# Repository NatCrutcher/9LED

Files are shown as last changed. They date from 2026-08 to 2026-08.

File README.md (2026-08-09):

## Overview

This is a small test PCB to experiment with wide color gamut LEDs. The initial plan is to use the following LEDs, driven by the TI TLC5971 (high-quality 16-bit PWM).

1. Violet 410 (XE-G)
2. Blue PC 460 (OSLON)
3. Cyan 500 (XE-G)
4. Green 525 (OSLON)
5. Yellow PC 590 (OSLON)
6. Red 620 (OSLON)
7. Photo Red 660 (XE-G)
8. Far Red 735 (Luxeon)
9. White (OSLON)

This should allow tests to compare more traditional RGB and RGBW color gamuts to wider gamuts. In particular, deeper reds, violet, and cyan. 

### Cyan
Initial testing shows that the cyan LED makes a color that is perceptually different from just mixing various amounts of green and blue. Green+blue results in the traditional computer monitor "cyan", which is really more turquoise. The pure cyan LED results in a more saturated (computer monitor cyan is a bit pastel by comparison) strong green-blue color.

### Violet

By itself, the violet LED is not what I expected: it seems almost like a purple/blue/white mixture. I need to do more research to make sure it is not exciting the phosphors in the white LED (perhaps build a board without the white). My plans are to compare purples (red+blue and red+violet) to see if violet generates noticeably different (i.e. more intense) purpl

### Photo Red and Far Red

This is an interesting example of how our eyes acclimate, color balance, and otherwise shift our perceptions. When I look at the normal red LED, it looks strongly red. But when I look at normal red next to photo red, the photo red looks more intensely red and the normal red starts to look like an orange-red. I want to try a larger experiment to determine how this effect scales.

The far red appears to be useless for LED sculptures, animations, or lighting. The perceived brightness is MUCH (like 10-20X) lower, so it can only produce very dim illumination. And as seen on the chromaticity diagrams, the perceived color is very close to photo red, so it does not meaningfully increase the gamut.

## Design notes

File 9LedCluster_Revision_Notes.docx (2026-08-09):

# 9 LED Cluster – Revision Notes

# Revision v1 – 2025-02-01

- First revision

# Revision v2 – 2025-09-22

## General

- No: Add some test points.
- DONE: Remove J1 and J2 pads from the paste mask.
- DONE: Move pad labels to the bottom so that I can make the board narrower. Or remove altogether.
- DONE: Document the mounting hole sizes on the schematic.
- DONE: Remove thermal reliefs for the mounting holes to the ground plane.
- DONE: Renumber designators.
- DONE: Try with 0603 to see if it makes the board larger.
- DONE: Change to 4-layer PCB.
- No: Consider metal core PCB
- Future: Add fiducials
- No: Try single-layer PCB design with zero-ohm jumpers instead of bottom layer tracks. This might allow an inexpensive metal core PCB and better heatsinking.
- DONE: Make room for a fourth corner hole.
- Future: Consider adding some thermistors to measure temperatures. Perhaps with I2C DAQ.

## Power Supply

- DONE: Update Vreg feedback calcs. R5 and R6 are reversed.
- DONE: Change to 4.0 V output.
- Skip for now: Can I find a buck converter with a higher switching frequency and a smaller inductor? – Yes, higher freq (2.0 MHz vs 1.1 MHz), the inductor drops from 15μH to 10μH, but ends up the same size. Consider integrated converter.
- Skip for now: Consider DC-DC module like TI TPSM33615.
- DONE: Replace R7 with a ferrite bead.
- Future: Consider one FB at J1 and one at J2. Or use CM choke at each end.
  - Murata BLM15AG601SH1D 0402, 600Ω @ 100 MHz, DCR=0.6Ω
- DONE: Route the Vin track on the third layer and further from the buck regulator to avoid noise coupling.
- Somewhat done: Surround the buck regulator switching nodes with ground.
- DONE: Consider an isolated ground plane with single connection for the buck regulator.
- Future: Test conducted RF from the regulator onto the Vin and Vout leads.
- DONE: Changed buck output cap from 1206 to 0805.
- DONE: Test at Vcc = 4.0 and 4.25 V to see how it affects the heating. Make sure we won’t overvoltage the SPI inputs (Vcc+0.6 abs max). Use the same Vcc for the level shifter.
  - Vcc = 4.0 V works well
- Future: Consider UVLO on the power supply
- DONE: Protect against reverse polarity connection, if not too difficult.
  - Diotec SKM14 Schottky, 40V, 1A, SOD-123FL, 350mV@1A

## LED Driver

- DONE: Disconnect VREG from VCC so the SPI levels will be 3.3V. Add a 1.0μF bypass cap on VREG.
- Future: Protect SDTI and SCKI from exceeding Vcc+0.6, perhaps with Schottky diodes or SOT-23 input protection diodes to Vcc. Maybe also series current limiting resistors.
- Future: Consider 3-terminal feed through capacitors. Maybe replace five 0.22uF with 1-2 three-terminal caps.
  - https://product.tdk.com/en/techlibrary/solutionguide/yff-series.html
- DONE: Add dropping diodes or resistors for lower Vf diodes, like red and amber. This will reduce the heating in the TLC5971. These could be populated with zero-ohm jumpers when not needed. It looks like 0603 resistors would be best, 16.0 or 16.5 ohm for 60 mA, only for LEDs with ~2.0 Vf.
  - Rohm ESR03EZPF16R5, 16.5Ω, 1%, 0.25W, 100 ppm/°C, thick film, 0603
  - Panasonic ERJ-PA3F16R0V, 16.0Ω, 1%, 0.33W, 100 ppm/°C, thick film, 0603
  - Vishay Dale CRCW06038R20FKEAHP, 8.2Ω, 1%, 0.33W, 100 ppm/°C, thick film, 0603
- Skip: Consider dual drivers to allow 2X the power. Would likely overheat the PCB and LEDs.

## LEDs

- DONE: Center LEDs on the PCB and align the corner holes to be symmetrical.
- DONE: Larger LED cathode mark in copper (it’s not really visible). Or remove and just use silkscreen.
- DONE: For the Luxeon CZ LEDs, make LED pads slightly taller, maybe 0.1 to 0.2 mm on each end (right now, they are fully covered on both ends).
- DONE: Consider LED diffuser mounting holes.
- DONE: Leave a clear margin around the LEDs for light shaping / diffusing
- DONE: Leave ~1mm between LEDs for barrier to block blue/violet from white phosphors. This may not be needed if I use flat top LEDs (no lens).
- DONE: Use a mixture of OSLON Pure 1414, Cree XE-G, and Luxeon CZ LED since we are only driving 60 mA to 120 mA. This will save money and space.
- DONE: Change to a shorter wavelength violet (410 nm instead of 425 nm)

# Revision v2b – 2025-10-08

## General

- Remove corner holes from the solder paste stencil.
- Adjust solder paste expansion.
- Adjust solder paste stencil size and thickness.

# Revision v3 – tbd

## Future

- Add fiducials

## LED List

1. Violet 410 (XE-G)
2. Blue PC 460 (OSLON)
3. Cyan 500 (XE-G)
4. Green 525 (OSLON)
5. Yellow PC 590 (OSLON)
6. Red 620 (OSLON)
7. Photo Red 660 (XE-G)
8. Far Red 735 (Luxeon)
9. White (OSLON)

Yellow PC | Red | Blue PC
White | Photo Red | Cyan
Green | Far Red | Violet

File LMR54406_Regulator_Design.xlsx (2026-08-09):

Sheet: Design
Inductor
Vout | Vin_max | L |  | fSW | ΔiL | Iout_max | K_IND | Lmin | Lrms | Lsat
4.5 | 25 | 1.5e-05 |  | 1100000 | 0.224 | 0.550 | 40.66115702% | 1.5e-05 | 0.825 | 1.375
4.0 | 25 | 1.5e-05 |  | 1100000 | 0.204 | 0.550 | 37.02479339% | 1.5e-05 | 0.825 | 1.375
Recheck the Lmin for 4.0 Vout
Regulator Feedback
R5 (R_FBT) | Vcc | R6 (R_FBB) Target | R6 Actual | R5+R6 Actual | Ifb | Pr5 | Pr6 | Pfb | Check Vcc
23200 | 5.0 | 121800 | 121000 | 144200 | 3.46740638e-05 | 2.789314425e-05 | 0.0001464390073 | 0.0001743321516 | 4.972
23200 | 4.5 | 107300 | 107000 | 130200 | 3.456221198e-05 | 2.771347873e-05 | 0.0001281748391 | 0.0001558883179 | 4.490
23200 | 4.0 | 92800 | 93100 | 116300 | 3.439380911e-05 | 2.744407125e-05 | 0.000109776285 | 0.0001372203562 | 4.010
23200 | 4.5 | 107300 | 107000 | 130200 | 3.456221198e-05 | 2.771347873e-05 | 0.0001281748391 | 0.0001558883179 | 4.490
23200 | 4.0 | 92800 | 93100 | 116300 | 3.439380911e-05 | 2.744407125e-05 | 0.000109776285 | 0.0001372203562 | 4.010
18000 | 4.0 | 72000 | 75000 | 93000 | 4.301075269e-05 | 3.329864724e-05 | 0.000133194589 | 0.0001664932362 | 4.133
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

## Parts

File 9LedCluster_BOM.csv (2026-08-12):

NccId | Qty | Reference | Value | Type | DNP | Manufacturer | MPN | Price10 | Rating | Tolerance | Rating2 | Description | Package | Footprint | Vendor1 | Vendor1PN | Vendor2 | Vendor2PN
p0F | 1 | D8 | Far Red | Luxeon C |  | Lumileds | L1C1-FRD1000000000 | 2.42 | 350mA |  |  | LED Luxeon C Far Red 2.0x2.0 350mA | LED 0808 | NwcPcbLibrary:Luxeon_CZ_LED_AK | Digi-Key | 1416-1913-1-ND | Mouser | 997-L1C1-FRD10000000
p03 | 1 | D7 | Green | Pure 1414 |  | ams-OSRAM | GT VJLPL1.13-LPLS-T3T4-1 | 1.01 | 350mA |  |  | LED Pure 1414 Green 1.4x1.4 350mA | LED 0505 | NwcPcbLibrary:OSRAM-OSLON-Pure-1414 | Digi-Key | 475-GTVJLPL1.13-LPLS-T3T4-1-350-R18CT-ND | Mouser | 720-GTVL113LPLST3T41
p04 | 1 | D2 | Red | Pure 1414 |  | ams-OSRAM | GR VJLPL1.23-KQKS-A4R2-1 | 1.04 | 350mA |  |  | LED Pure 1414 Red 1.4x1.4 350mA | LED 0505 | NwcPcbLibrary:OSRAM-OSLON-Pure-1414 | Digi-Key | 475-GRVJLPL1.23-KQKS-A4R2-1-350-R18CT-ND | Mouser | 720-GRVL123KQKSA4R21
p05 | 1 | D4 | White 4000K | Pure 1414 |  | ams-OSRAM | GW VJLPL1.CM-K3LX-XX55-1 | 1.013 | 350mA |  |  | LED Pure 1414 White 4000K 1.4x1.4 350mA | LED 0505 | NwcPcbLibrary:OSRAM-OSLON-Pure-1414 | Digi-Key | 475-GWVJLPL1.CM-K3LX-XX55-1-350-R18CT-ND | Mouser | 720-GWVL1CMK3LXXX551
p15 | 1 | D1 | Yellow PC | Pure 1414 |  | ams-OSRAM | GY VJLPL1.F3-KULQ-YCYK-1 | 0.748 | 350mA |  |  | LED Pure 1414 Yellow PC 1.4x1.4 350mA | LED 0505 | NwcPcbLibrary:OSRAM-OSLON-Pure-1414 | Digi-Key | 475-GYVJLPL1.F3-KULQ-YCYK-1-350-R18CT-ND | Mouser | 720-GYVL1F3KULQYCYK1
p16 | 1 | D9 | PC Blue | Pure 1414 |  | ams-OSRAM | GB VJLPL1.F3-JRJT-BABB-1 | 1.024 | 350mA |  |  | LED Pure 1414 PC Blue 1.4x1.4 350mA | LED 0505 | NwcPcbLibrary:OSRAM-OSLON-Pure-1414 | Digi-Key | 475-GBVJLPL1.F3-JRJT-BABB-1CT-ND | Mouser | 720-GBVL1F3JRJTBABB1
p17 | 1 | D3 | Violet | XE-G |  | Cree | XEGAVT-H0-0000-000-000000K2001 | 3.819 | 1A |  |  | LED XE-G Violet 2.05x1.6 1A | LED 0806 | NwcPcbLibrary:Cree_XE-G | Digi-Key | 90-XEGAVT-H2-0000-000-000000K2001CT-ND | Mouser | 941-XEGAVTH000K2001
p18 | 1 | D5 | Photo Red | XE-G |  | Cree | XEGAHR-H2-0000-000-000000H6001 | 2.73 | 1A |  |  | LED XE-G Photo Red 2.05x1.6 1A | LED 0806 | NwcPcbLibrary:Cree_XE-G | Digi-Key | 90-XEGAHR-H2-0000-000-000000H6001CT-ND | Mouser | 941-XEGAHRH200H6001
p19 | 1 | D6 | Cyan | XE-G |  | Cree | XEGACY-H2-0000-000-000000T3001 | 3 | 1A |  |  | LED XE-G Cyan 2.05x1.6 1A | LED 0806 | NwcPcbLibrary:Cree_XE-G | Digi-Key | 90-XEGACY-H0-0000-000-000000S5001CT-ND | Mouser | 941-XEGACYH20T3001
n05 | 1 | L1 | 15uH | Shielded, drum |  | TDK | BCL322520RT-150M-D | 1.09 | I=1.47 | 20% | 320 mOhm Max | inductor 15uH Shielded, drum 3.2x2.5 I=1.47 | Ind 3.2x2.5mm | Inductor_SMD:L_1210_3225Metric | Digi-Key | 445-BCL322520RT-150M-DCT-ND | Mouser | 810-BCL322520RT150MD
n07 | 1 | FB1 | 600Ω | Ferrite Bead |  | Murata Electronics | BLM18KG601SN1D | 0.062 | 1.3A |  | DCR=150mΩ | ferrite 600Ω 0603 1.3A | 0603 | Resistor_SMD:R_0603_1608Metric_Pad0.98x0.95mm_HandSolder | Digi-Key | 490-5258-1-ND
k05 | 1 | U2 | TLC5971 | LED PWM driver |  | TI | TLC5971RGER | 2.342 | 17V, 60mA |  | 12ch, 16bit | IC TLC5971 LED PWM driver VQFN-24 4x4mm_P0.5mm TI | VQFN-24 4x4mm_P0.5mm | Package_DFN_QFN:Texas_RGE0024H_VQFN-24-1EP_4x4mm_P0.5mm_EP2.7x2.7mm_ThermalVias | Digi-Key | 296-28448-1-ND | Mouser | 595-TLC5971RGER
k16 | 1 | U1 | LMR54406 | Regulator, Buck |  | TI | LMR54406DBVR | 0.86 | 1.1MHz |  | 600mA | IC LMR54406 Regulator, Buck SOT-23-6 TI | SOT-23-6 | Package_TO_SOT_SMD:SOT-23-6 | Digi-Key | 296-LMR54406DBVRCT-ND | Mouser | 595-LMR54406DBVR
a0B | 1 | C3 | 2.2u | X7R |  | Taiyo Yuden | UMK212BB7225KG-T | 0.192 | 50V | 10% |  | capacitor 2.2u C0805 X7R 50V 10% | C0805 | Capacitor_SMD:C_0805_2012Metric | Digi-Key | 587-3169-1-ND | Mouser | 963-UMK212BB7225KG-T
a07 | 2 | C1,C2 | 0.1u | X7R |  | Murata Electronics | GRM155R71H104KE14D | 0.025 | 50V | 10% | C@24V>=0.039uF | capacitor 0.1u C0402 X7R 50V 10% | C0402 | Capacitor_SMD:C_0402_1005Metric | Digi-Key | 490-10700-1-ND | Mouser | 81-GRM155R71H104KE4D
a09 | 1 | C7 | 1.0u | X7R |  | Taiyo Yuden | TMK107B7105KA-T | 0.012 | 25V | 10% | C@5V>=0.072uF | capacitor 1.0u C0603 X7R 25V 10% | C0603 | Capacitor_SMD:C_0603_1608Metric | Digi-Key | 587-2984-1-ND | Mouser | 963-TMK107B7105KA-T
a14 | 3 | C5,C6,C8 | 0.22u | X7R |  | KEMET | C0402C224M4RACTU | 0.169 | 16V | 20% |  | capacitor 0.22u C0402 X7R 16V 20% | C0402 | Capacitor_SMD:C_0402_1005Metric | Digi-Key | 399-C0402C224M4RACTUCT-ND | Mouser | 80-C0402C224M4RACTU
a17 | 1 | C4 | 22u | X7R |  | Murata Electronics | GRM21BZ71A226ME15L | 0.182 | 10V | 20% | C@4V>=12uF | capacitor 22u C0805 X7R 10V 20% | C0805 | Capacitor_SMD:C_0805_2012Metric | Digi-Key | 490-GRM21BZ71A226ME15LCT-ND | Mouser | 81-GRM21BZ71A226ME5L
d04 | 4 | Z1,Z2,Z3,Z4 | 5.5V | TVS |  | KYOCERA AVX | GG040205100N2P | 0.127 | 5.5V, 10pF |  | 25kV ESD | diode 5.5V TVS TVS-0402 5.5V, 10pF | TVS-0402 | Resistor_SMD:R_0402_1005Metric | Digi-Key | 478-10594-1-ND | Mouser | 581-GG040205100N2P
d06 | 1 | D10 | SKM14 | Schottky |  | Diotec Semiconductor | SKM14 | 0.186 | 40V, 1A |  | 350mV @ 1A | diode SKM14 Schottky SOD-123F 40V, 1A | SOD-123F | Diode_SMD:D_SOD-123F | Digi-Key | 4878-SKM14CT-ND | Mouser | 637-SKM14
r0B | 1 | R7 | 825R | Thin film |  | Susumu | RR0510P-8250-D | 0.024 | 0.063W | 1% | 25ppm/C | resistor 825R R0402 1% Thin film | R0402 | Resistor_SMD:R_0402_1005Metric | Digi-Key | 408-RR0510P-8250-DCT-ND | Mouser | 754-RR0510P-8250D
r1B | 1 | R2 | 0R | Thick film | DNP | KOA Speer | RK73Z1ETTP | 0.008 |  | jumper |  | resistor 0R R0402 jumper Thick film | R0402 | Resistor_SMD:R_0402_1005Metric | Digi-Key | 2019-RK73Z1ETTPCT-ND | Mouser | 660-RK73Z1ETTP
r1C | 2 | R4,R5 | 27R | Thin film |  | YAGEO | RT0402FRE0727RL | 0.021 | 0.063W | 1% | 50ppm/C | resistor 27R R0402 1% Thin film | R0402 | Resistor_SMD:R_0402_1005Metric | Digi-Key | YAG3343CT-ND | Mouser | 603-RT0402FRE0727RL
r14 | 1 | R3 | 100k | Thin film |  | YAGEO | RT0603DRD07100KL | 0.048 | 0.1W | 0.5% | 25ppm/C | resistor 100k R0603 0.5% Thin film | R0603 | Resistor_SMD:R_0603_1608Metric | Digi-Key | 311-100KDCT-ND | Mouser | 603-RT0603DRD07100KL
r22 | 1 | R1 | 24.9k | Thin film |  | Susumu | RR0816P-2492-D-39C | 0.025 | 0.063W | 0.5% | 25ppm/C | resistor 24.9k R0603 0.5% Thin film | R0603 | Resistor_SMD:R_0603_1608Metric | Digi-Key | RR08P24.9KDCT-ND | Mouser | 754-RR0816P-2492D39C
r25 | 1 | R6 | 10R | Thick film |  | KOA Speer | RK73H1JTTD10R0F | 0.016 | 0.125W | 1% | 100ppm/C | resistor 10R R0603 1% Thick film | R0603 | Resistor_SMD:R_0603_1608Metric | Digi-Key | 2019-RK73H1JTTD10R0FCT-ND | Mouser | 660-RK73H1JTTD10R0F
r26 | 2 | R8,R9 | 12R | Thick film |  | KOA Speer | RK73H1JTTD12R0F | 0.026 | 0.125W | 1% | 100ppm/C | resistor 12R R0603 1% Thick film | R0603 | Resistor_SMD:R_0603_1608Metric | Digi-Key | 2019-RK73H1JTTD12R0FCT-ND | Mouser | 660-RK73H1JTTD12R0F

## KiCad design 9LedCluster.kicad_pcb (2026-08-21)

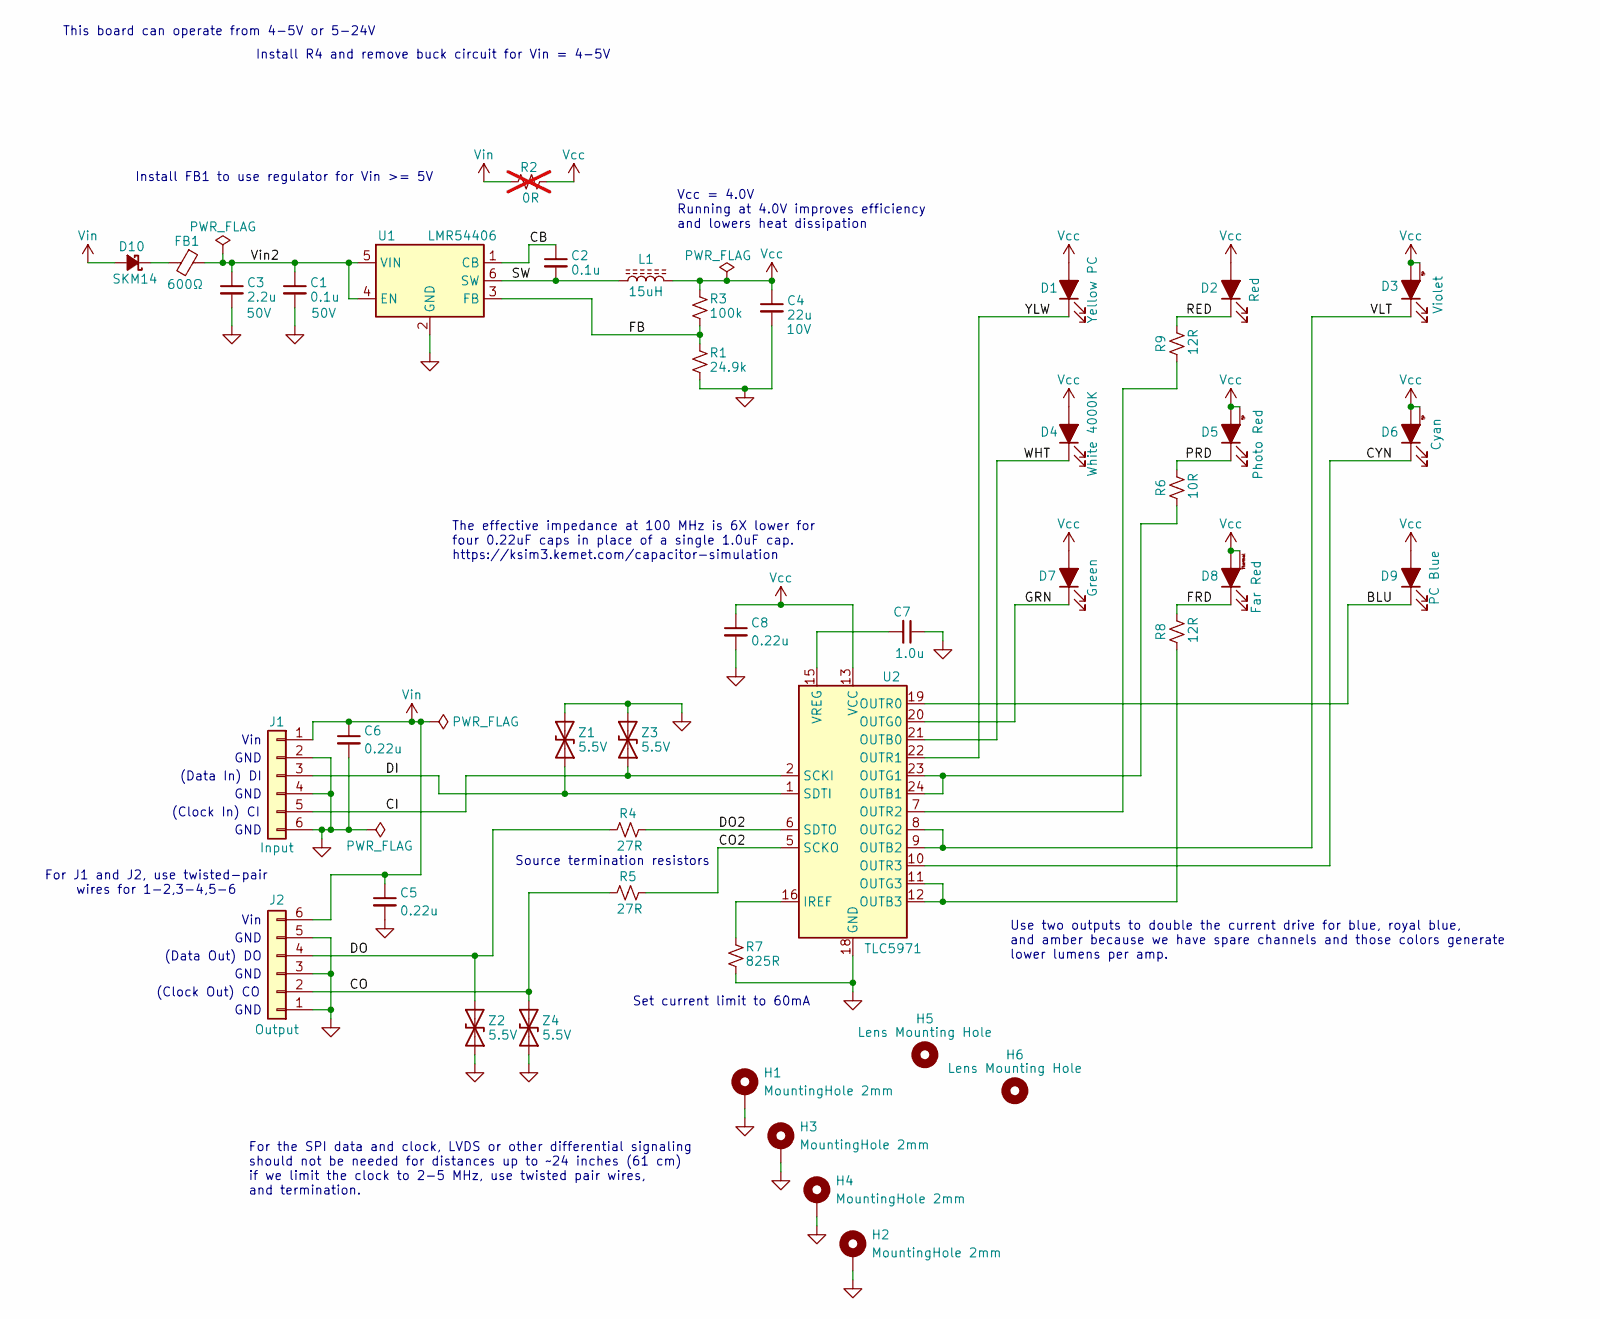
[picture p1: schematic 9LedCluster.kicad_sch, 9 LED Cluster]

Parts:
C1, C2: 0.1u; C_0402_1005Metric; Rating 50V; Tolerance 10%; MPN GRM155R71H104KE14D
C3: 2.2u; C_0805_2012Metric; Rating 50V; Tolerance 10%; MPN UMK212BB7225KG-T
C4: 22u; C_0805_2012Metric; Rating 10V; Tolerance 20%; MPN GRM21BZ71A226ME15L
C5, C6, C8: 0.22u; C_0402_1005Metric; Rating 16V; Tolerance 20%; MPN C0402C224M4RACTU
C7: 1.0u; C_0603_1608Metric; Rating 25V; Tolerance 10%; MPN TMK107B7105KA-T
D1: Yellow PC; OSRAM-OSLON-Pure-1414; Rating 350mA; MPN GY VJLPL1.F3-KULQ-YCYK-1
D2: Red; OSRAM-OSLON-Pure-1414; Rating 350mA; MPN GR VJLPL1.23-KQKS-A4R2-1
D3: Violet; Cree_XE-G; Rating 1A; MPN XEGAVT-H0-0000-000-000000K2001
D4: White 4000K; OSRAM-OSLON-Pure-1414; Rating 350mA; MPN GW VJLPL1.CM-K3LX-XX55-1
D5: Photo Red; Cree_XE-G; Rating 1A; MPN XEGAHR-H2-0000-000-000000H6001
D6: Cyan; Cree_XE-G; Rating 1A; MPN XEGACY-H2-0000-000-000000T3001
D7: Green; OSRAM-OSLON-Pure-1414; Rating 350mA; MPN GT VJLPL1.13-LPLS-T3T4-1
D8: Far Red; Luxeon_CZ_LED_AK; Rating 350mA; MPN L1C1-FRD1000000000
D9: PC Blue; OSRAM-OSLON-Pure-1414; Rating 350mA; MPN GB VJLPL1.F3-JRJT-BABB-1
D10: SKM14; D_SOD-123F; Rating 40V, 1A; Rating2 350mV @ 1A; MPN SKM14
FB1: 600Ω; R_0603_1608Metric_Pad0.98x0.95mm_HandSolder; Rating 1.3A; Rating2 DCR=150mΩ; MPN BLM18KG601SN1D
H1, H2, H3, H4: MountingHole 2mm; MountingHole_2.0mm_A
H5, H6: Lens Mounting Hole; MountingHole_2.0mm_NP
J1: Input; Conn_2.00mm_6_LED
J2: Output; Conn_2.00mm_6_LED
L1: 15uH; L_1210_3225Metric; Rating I=1.47; Rating2 320 mOhm Max; MPN BCL322520RT-150M-D
R1: 24.9k; R_0603_1608Metric; Tolerance 0.5%; Rating 0.063W; MPN RR0816P-2492-D-39C
R2: 0R; R_0402_1005Metric; Tolerance jumper; MPN RK73Z1ETTP; not fitted
R3: 100k; R_0603_1608Metric; Tolerance 0.5%; Rating 0.1W; MPN RT0603DRD07100KL
R4, R5: 27R; R_0402_1005Metric; Tolerance 1%; Rating 0.063W; MPN RT0402FRE0727RL
R6: 10R; R_0603_1608Metric; Tolerance 1%; Rating 0.125W; MPN RK73H1JTTD10R0F
R7: 825R; R_0402_1005Metric; Tolerance 1%; Rating 0.063W; MPN RR0510P-8250-D
R8, R9: 12R; R_0603_1608Metric; Tolerance 1%; Rating 0.125W; MPN RK73H1JTTD12R0F
U1: LMR54406; SOT-23-6; Rating 1.1MHz; Rating2 600mA; MPN LMR54406DBVR
U2: TLC5971; Texas_RGE0024H_VQFN-24-1EP_4x4mm_P0.5mm_EP2.7x2.7mm_Thermal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; Rating 17V, 60mA; Rating2 12ch, 16bit; MPN TLC5971RGER
Z1, Z2, Z3, Z4: 5.5V; R_0402_1005Metric; Rating 5.5V, 10pF; Rating2 25kV ESD; MPN GG040205100N2P

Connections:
/BLU: D9.K, U2.19 (OUTR0)
/CB: C2.1, U1.1 (CB)
/CI: J1.5, U2.2 (SCKI), Z3.1 (A1)
/CO: J2.2, R5.1, Z4.2 (A2)
/CO2: R5.2, U2.5 (SCKO)
/CYN: D6.K, U2.10 (OUTR3)
/DI: J1.3, U2.1 (SDTI), Z1.1 (A1)
/DO: J2.4, R4.1, Z2.2 (A2)
/DO2: R4.2, U2.6 (SDTO)
/FB: R1.1, R3.2, U1.3 (FB)
/FRD: D8.K, R8.2
/GRN: D7.K, U2.20 (OUTG0)
/PRD: D5.K, R6.2
/RED: D2.K, R9.2
/SW: C2.2, L1.1, U1.6 (SW)
/VLT: D3.K, U2.8 (OUTG2), U2.9 (OUTB2)
/Vin2: C1.1, C3.1, FB1.1, U1.4 (EN), U1.5 (VIN)
/WHT: D4.K, U2.21 (OUTB0)
/YLW: D1.K, U2.22 (OUTR1)
GND: C1.2, C3.2, C4.2, C5.2, C6.2, C7.1, C8.2, H1.1, H2.1, H3.1, H4.1, J1.2, J1.4, J1.6, J2.1, J2.3, J2.5, R1.2, R7.2, U1.2 (GND), U2.18 (GND), U2.25 (GND), Z1.2 (A2), Z2.1 (A1), Z3.2 (A2), Z4.1 (A1)
unnamed: D10.1 (K), FB1.2
unnamed: R7.1, U2.16 (IREF)
unnamed: R6.1, U2.23 (OUTG1), U2.24 (OUTB1)
unnamed: R8.1, U2.11 (OUTG3), U2.12 (OUTB3)
unnamed: R9.1, U2.7 (OUTR2)
unnamed: C7.2, U2.15 (VREG)
Vcc: C4.1, C8.1, D1.A, D2.A, D3.A, D3.TP, D4.A, D5.A, D5.TP, D6.A, D6.TP, D7.A, D8.A, D8.TP, D9.A, L1.2, R2.2, R3.1, U2.13 (VCC)
Vin: C5.1, C6.1, D10.2 (A), J1.1, J2.6, R2.1

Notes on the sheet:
(Clock In) CI
(Data Out) DO
Vin
GND
For the SPI data and clock, LVDS or other differential signaling should not be needed for distances up to ~24 inches (61 cm) if we limit the clock to 2-5 MHz, use twisted pair wires, and termination.
Use two outputs to double the current drive for blue, royal blue, and amber because we have spare channels and those colors generate lower lumens per amp.
Install FB1 to use regulator for Vin >= 5V
This board can operate from 4-5V or 5-24V
For J1 and J2, use twisted-pair wires for 1-2,3-4,5-6
Source termination resistors
The effective impedance at 100 MHz is 6X lower for four 0.22uF caps in place of a single 1.0uF cap. https://ksim3.kemet.com/capacitor-simulation
Install R4 and remove buck circuit for Vin = 4-5V
(Data In) DI
(Clock Out) CO
Vcc = 4.0V Running at 4.0V improves efficiency and lowers heat dissipation
Set current limit to 60mA

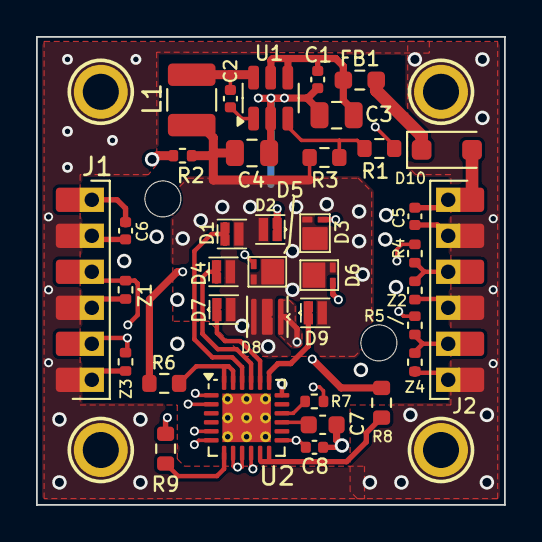
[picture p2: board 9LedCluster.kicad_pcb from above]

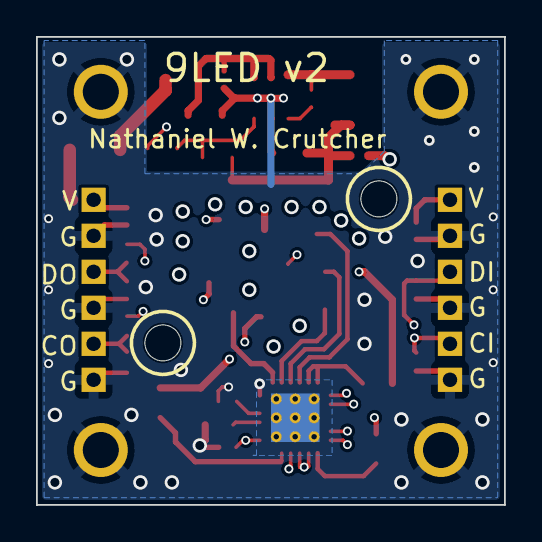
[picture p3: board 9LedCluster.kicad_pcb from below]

Board: 4 copper layers, 26.0 x 26.0 mm, 45 parts (2 on the bottom side), 28 nets.

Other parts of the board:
FID1, FID2: Fiducial_0402_Pad

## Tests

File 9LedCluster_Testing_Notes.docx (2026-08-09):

# 9 LED Cluster V2b Testing

# General

- Works with LED Sculpture Controller (Teensy) V1
- Vcc ~= 4.0 V
- Vreg (SPI) = 3.3 V
- The far red is very faint, perhaps not useful
- The Oslon red is more of an orange red, which could be fine.
- With both far red lines driven at 65000 (brightness=127), R8 reaches 49°C, U2 reaches 41°C

# Soldering

- The failures on SN #3 were both due to apparent solder bridges which appeared to be caused by too much solder paste.
- It is possible to remove LEDs with the hot air rework tool, but it seems likely to damage the top plastic of the LED. I think bottom side heat might be better, or both. I somewhat doubt that I could solder on a new LED with the hot air gun unless I also used bottom side heat.

# SN #1

- Yellow LED does not work

# SN #2

- Failed to power up on first attempt, then powered up
- Red LED does not work

# SN #3

- Cyan and white do not work - removed

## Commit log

2026-08-09 Initial Git commit at version V2b.
    [9LedCluster.kicad_pcb, 9LedCluster.kicad_sch, 9LedCluster_BOM.csv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]
2026-08-09 Update to KiCAD v10. Set PCB placement origin. Export placement file.
    [9LedCluster.kicad_pcb, 9LedCluster.kicad_sch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]
2026-08-12 Update parts to use new NCC library symbols, but keep footprints unchanged. Delete obsolete placement file. Regenerate BOM.
    [9LedCluster.kicad_pcb, 9LedCluster.kicad_sch, 9LedCluster_BOM.csv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]
2026-08-21 Fix center ref for CREE LEDs for 9LED.
    [9LedCluster.kicad_pcb]
